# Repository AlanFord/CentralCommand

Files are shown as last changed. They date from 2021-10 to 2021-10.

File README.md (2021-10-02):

# CentralCommand
Central Command pcb for the Contextual Electronics class

The objective of this portion of the class was to design and build
a development board based on the STM32F030 MCU.  USB functionality
is provided via an FTDI FT232RQ device attached to USART2.
An 8Mhz external clock is provided by a crystal.  External headers
are provided for USART1, I2C2, SPI1, ADC, and a programming connection.
I2C1 functionality is provided via two JST SH connectors.  One user
LED is provided.  An on-board reset button will reset the mcu.

The board can be powered either by the USB connection or via an external power supply providing
between 3.75 and 6V.  The voltage regulator can provide a maximum of
250 mA at 3.3V.

**UPDATE:**  The board should be powered through the external power connection
P202 when the board is being programmed.  If the board is powered via the USB
connector during programming, the trace between the reset button, SW301, and
the FTD232RQ USB interface must be cut.  Without cutting this trace the mcu reset
that occurs during programming will simultaneously reset the FTD232RQ device,
momentarily powering down the entire board.

**UPDATE #2:**  The firmware folders and files have been restructured
and updated to support the use of the STM32CubeIDE.  To use the IDE,
simply create a workspace and import this project.

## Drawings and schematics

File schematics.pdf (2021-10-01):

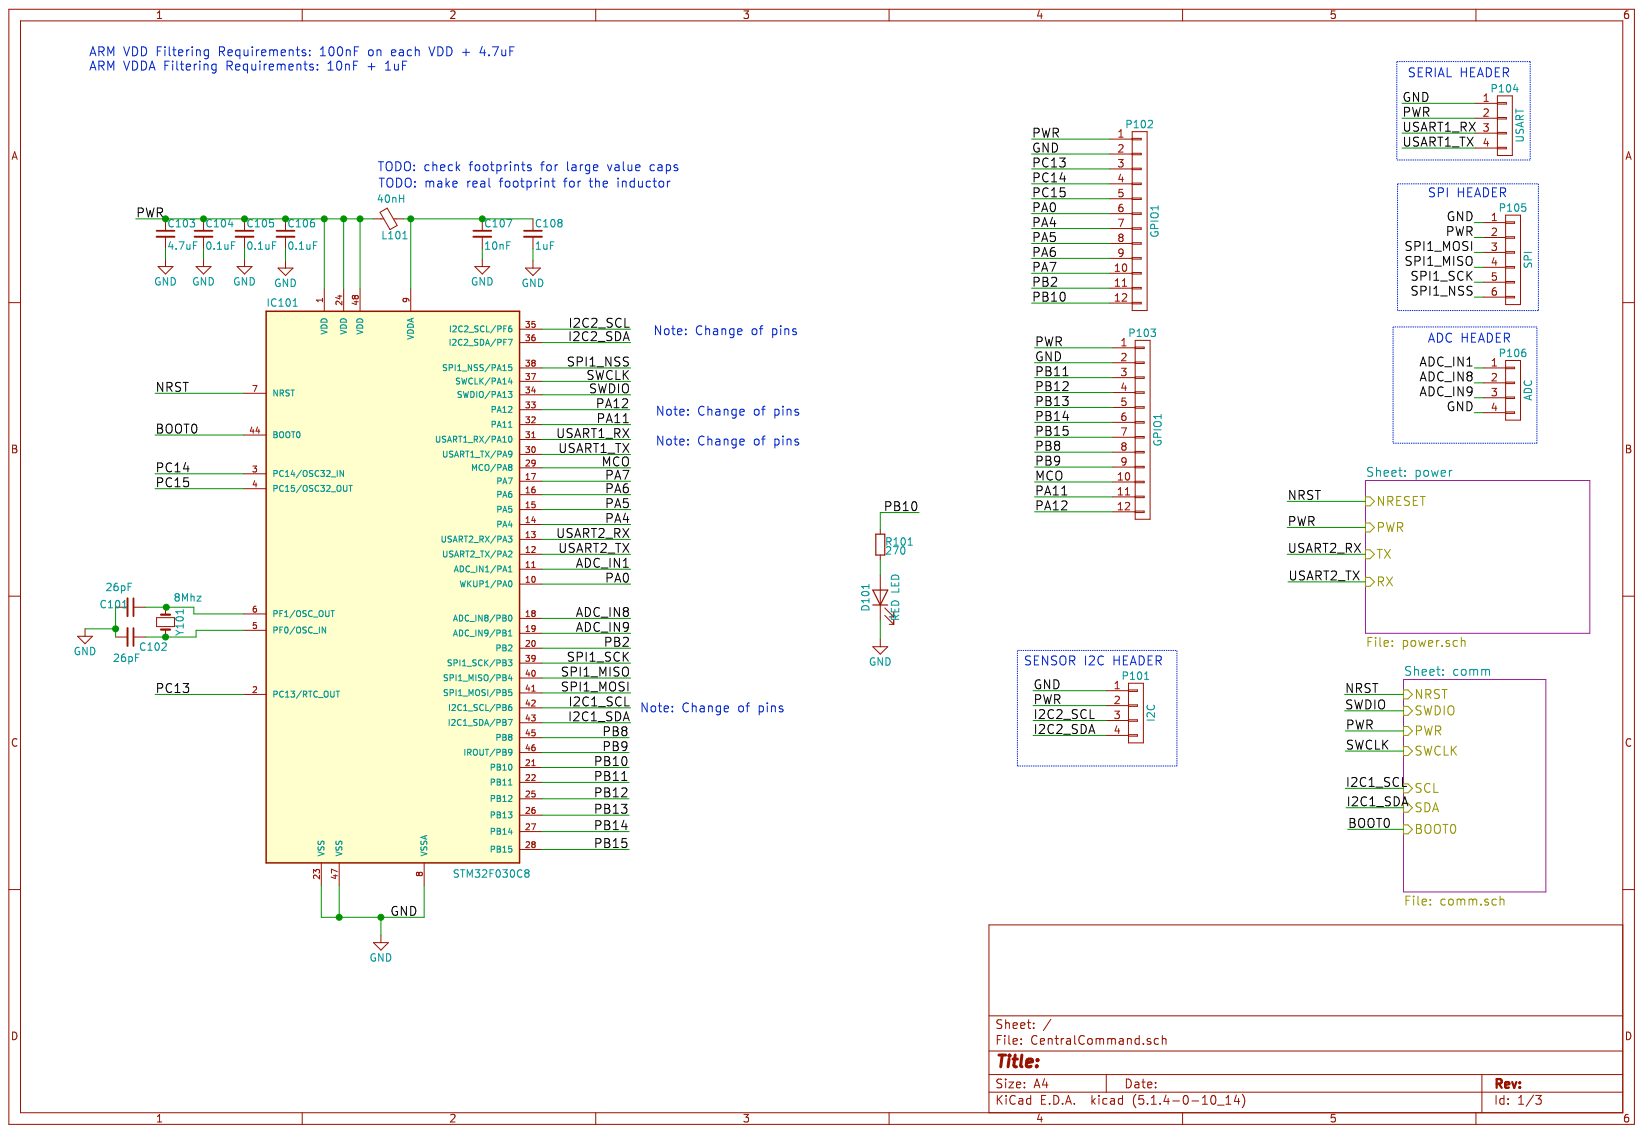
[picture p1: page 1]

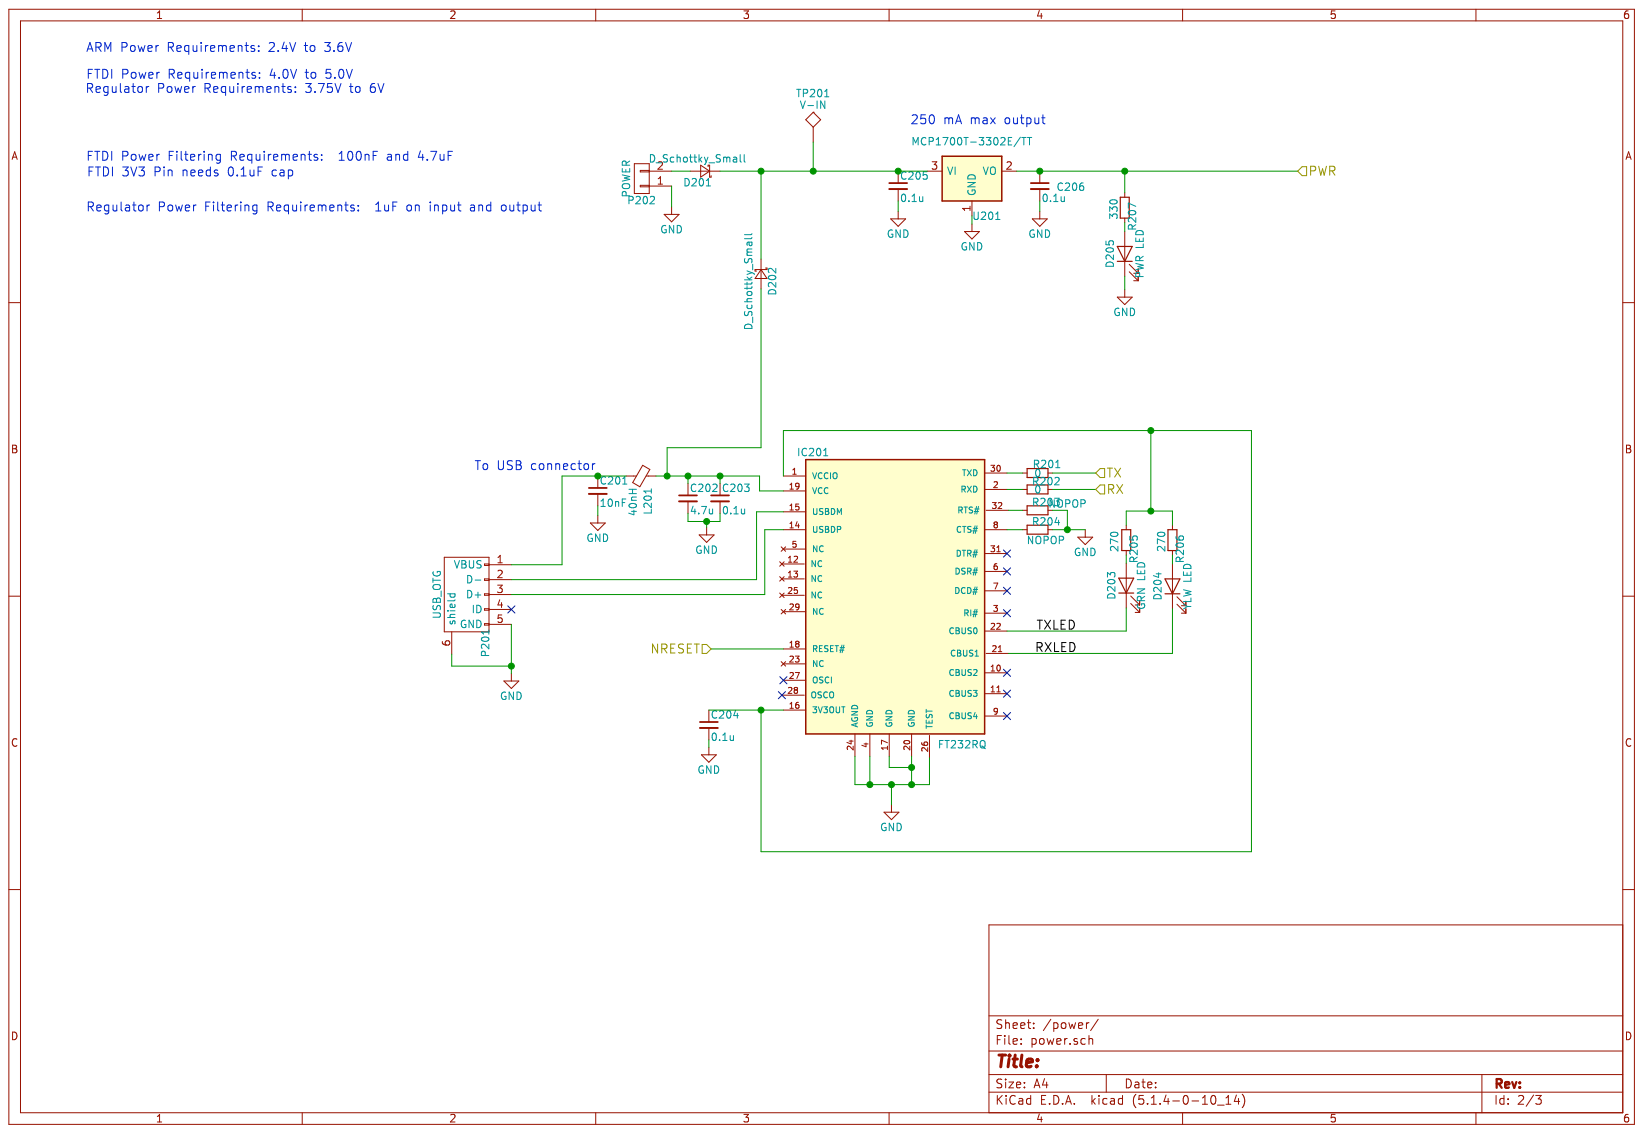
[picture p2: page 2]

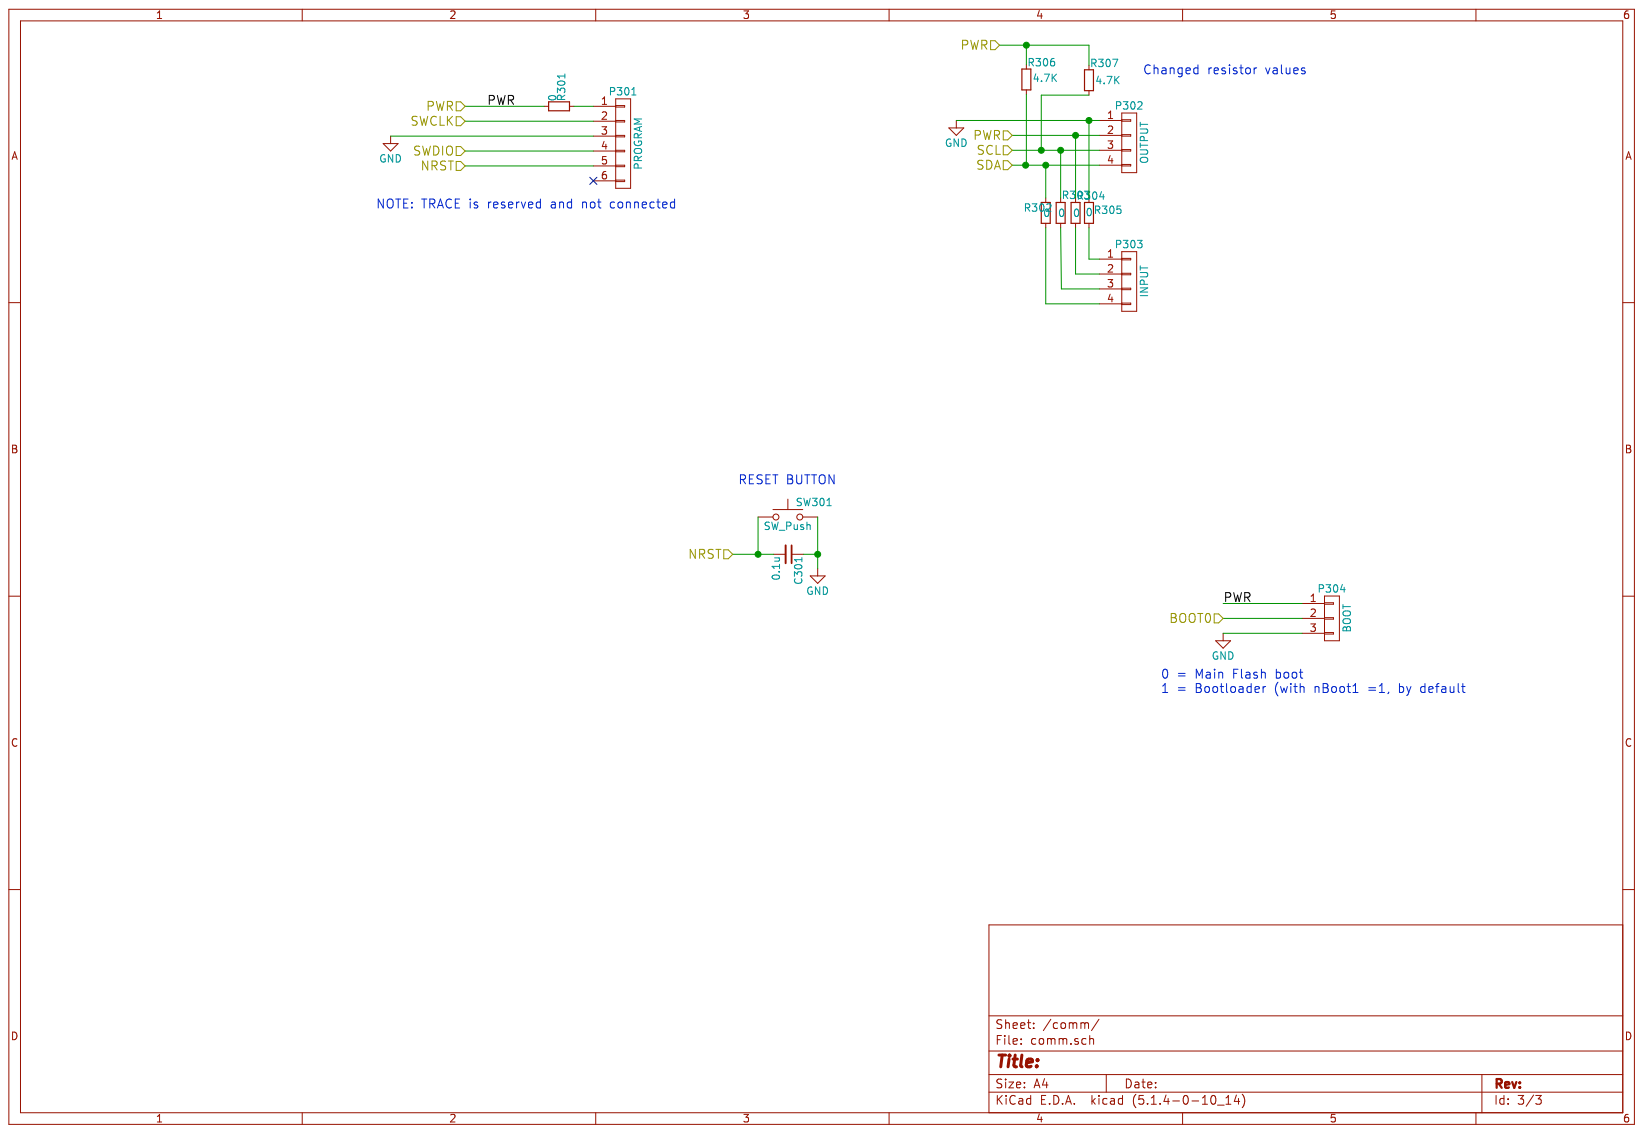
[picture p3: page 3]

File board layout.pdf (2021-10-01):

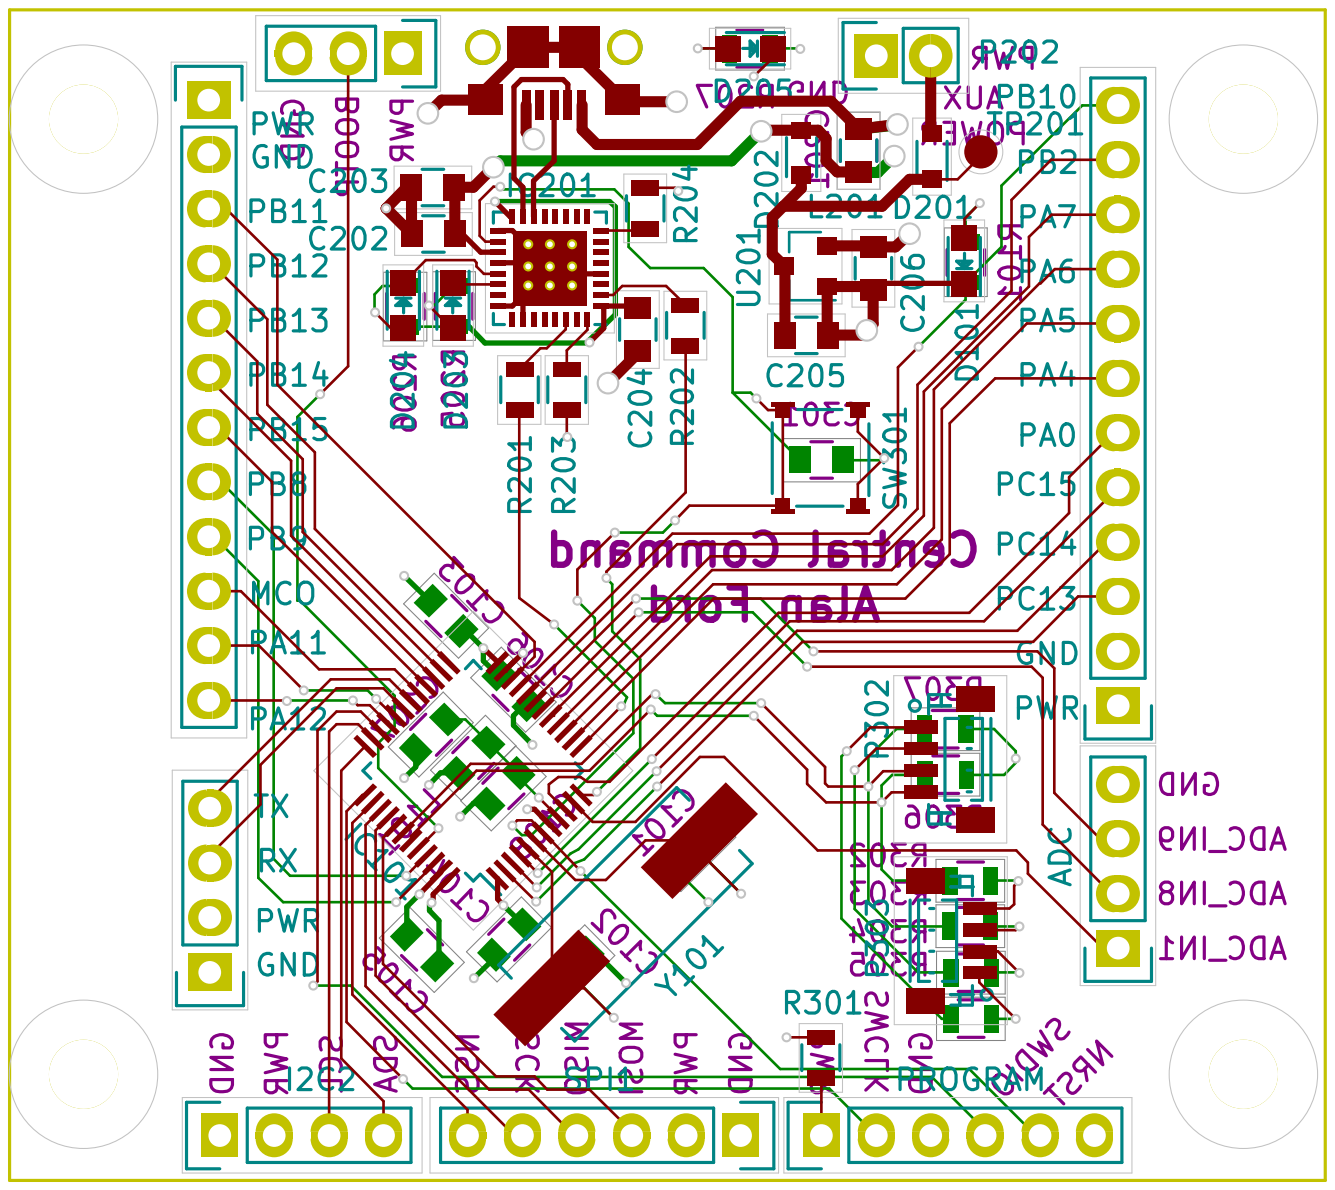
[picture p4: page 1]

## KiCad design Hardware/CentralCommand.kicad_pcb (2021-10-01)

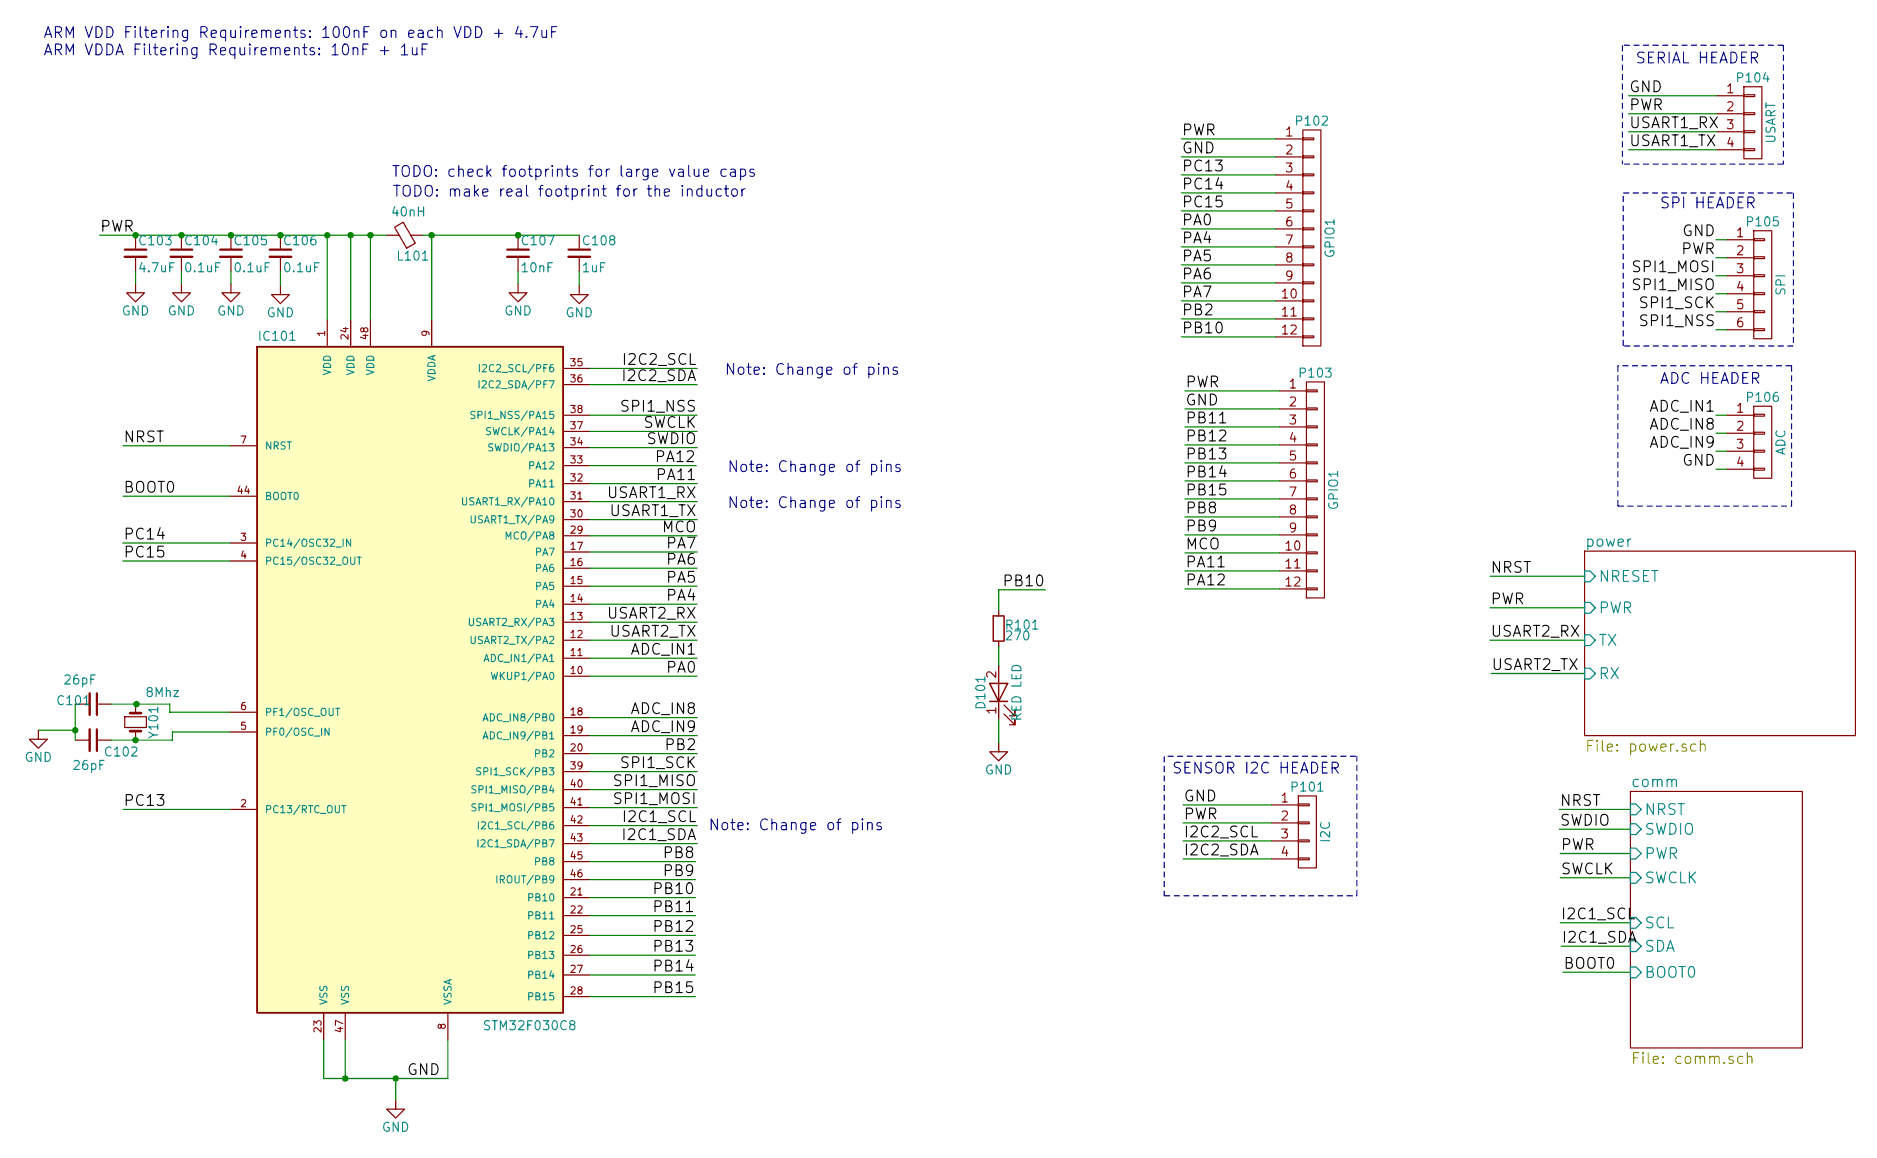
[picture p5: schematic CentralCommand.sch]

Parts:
C101, C102: 26pF; C_0805
C103: 4.7uF; C_0805
C104, C105, C106: 0.1uF; C_0805
C107: 10nF; C_0805
C108: 1uF; C_0805
D101: RED LED; LED_0805
IC101: STM32F030C8; LQFP-48_7x7mm_Pitch0.5mm; MPN STM32F030C8T6
L101: 40nH; C_0805; MPN MI0805K400R-10
P101: I2C; Pin_Header_Straight_1x04
P102, P103: GPIO1; Pin_Header_Straight_1x12
P104: USART; Pin_Header_Straight_1x04
P105: SPI; Pin_Header_Straight_1x06
P106: ADC; Pin_Header_Straight_1x04
R101: 270; R_0805
Y101: 8Mhz; Crystal_HC49-SD_SMD; MPN 9C-8.000MEEJ-T

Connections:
/ADC_IN1: IC101.11 (ADC_IN1/PA1), P106.1
/ADC_IN8: IC101.18 (ADC_IN8/PB0), P106.2
/ADC_IN9: IC101.19 (ADC_IN9/PB1), P106.3
/BOOT0: IC101.44 (BOOT0); also elsewhere on the board
/I2C1_SCL: IC101.42 (I2C1_SCL/PB6); also elsewhere on the board
/I2C1_SDA: IC101.43 (I2C1_SDA/PB7); also elsewhere on the board
/I2C2_SCL: IC101.35 (I2C2_SCL/PF6), P101.3
/I2C2_SDA: IC101.36 (I2C2_SDA/PF7), P101.4
/MCO: IC101.29 (MCO/PA8), P103.10
/NRST: IC101.7 (NRST); also elsewhere on the board
/PA0: IC101.10 (WKUP1/PA0), P102.6
/PA4: IC101.14 (PA4), P102.7
/PA5: IC101.15 (PA5), P102.8
/PA6: IC101.16 (PA6), P102.9
/PA7: IC101.17 (PA7), P102.10
/PA11: IC101.32 (PA11), P103.11
/PA12: IC101.33 (PA12), P103.12
/PB2: IC101.20 (PB2), P102.11
/PB8: IC101.45 (PB8), P103.8
/PB9: IC101.46 (IROUT/PB9), P103.9
/PB10: IC101.21 (PB10), P102.12, R101.1
/PB11: IC101.22 (PB11), P103.3
/PB12: IC101.25 (PB12), P103.4
/PB13: IC101.26 (PB13), P103.5
/PB14: IC101.27 (PB14), P103.6
/PB15: IC101.28 (PB15), P103.7
/PC13: IC101.2 (PC13/RTC_OUT), P102.3
/PC14: IC101.3 (PC14/OSC32_IN), P102.4
/PC15: IC101.4 (PC15/OSC32_OUT), P102.5
/PWR: C103.1, C104.1, C105.1, C106.1, IC101.1 (VDD), IC101.24 (VDD), IC101.48 (VDD), L101.2, P101.2, P102.1, P103.1, P104.2, P105.2; also elsewhere on the board
/SPI1_MISO: IC101.40 (SPI1_MISO/PB4), P105.4
/SPI1_MOSI: IC101.41 (SPI1_MOSI/PB5), P105.3
/SPI1_NSS: IC101.38 (SPI1_NSS/PA15), P105.6
/SPI1_SCK: IC101.39 (SPI1_SCK/PB3), P105.5
/SWCLK: IC101.37 (SWCLK/PA14); also elsewhere on the board
/SWDIO: IC101.34 (SWDIO/PA13); also elsewhere on the board
/USART1_RX: IC101.31 (USART1_RX/PA10), P104.3
/USART1_TX: IC101.30 (USART1_TX/PA9), P104.4
/USART2_RX: IC101.13 (USART2_RX/PA3); also elsewhere on the board
/USART2_TX: IC101.12 (USART2_TX/PA2); also elsewhere on the board
GND: C101.2, C102.2, C103.2, C104.2, C105.2, C106.2, C107.2, C108.2, D101.1 (K), IC101.8 (VSSA), IC101.23 (VSS), IC101.47 (VSS), P101.1, P102.2, P103.2, P104.1, P105.1, P106.4; also elsewhere on the board
unnamed: C101.1, IC101.6 (PF1/OSC_OUT), Y101.1
unnamed: C102.1, IC101.5 (PF0/OSC_IN), Y101.2
unnamed: C107.1, C108.1, IC101.9 (VDDA), L101.1
unnamed: D101.2 (A), R101.2

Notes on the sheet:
ARM VDD Filtering Requirements: 100nF on each VDD + 4.7uF ARM VDDA Filtering Requirements: 10nF + 1uF
SERIAL HEADER
SPI HEADER
ADC HEADER
SENSOR I2C HEADER
Note: Change of pins
TODO: make real footprint for the inductor
TODO: check footprints for large value caps

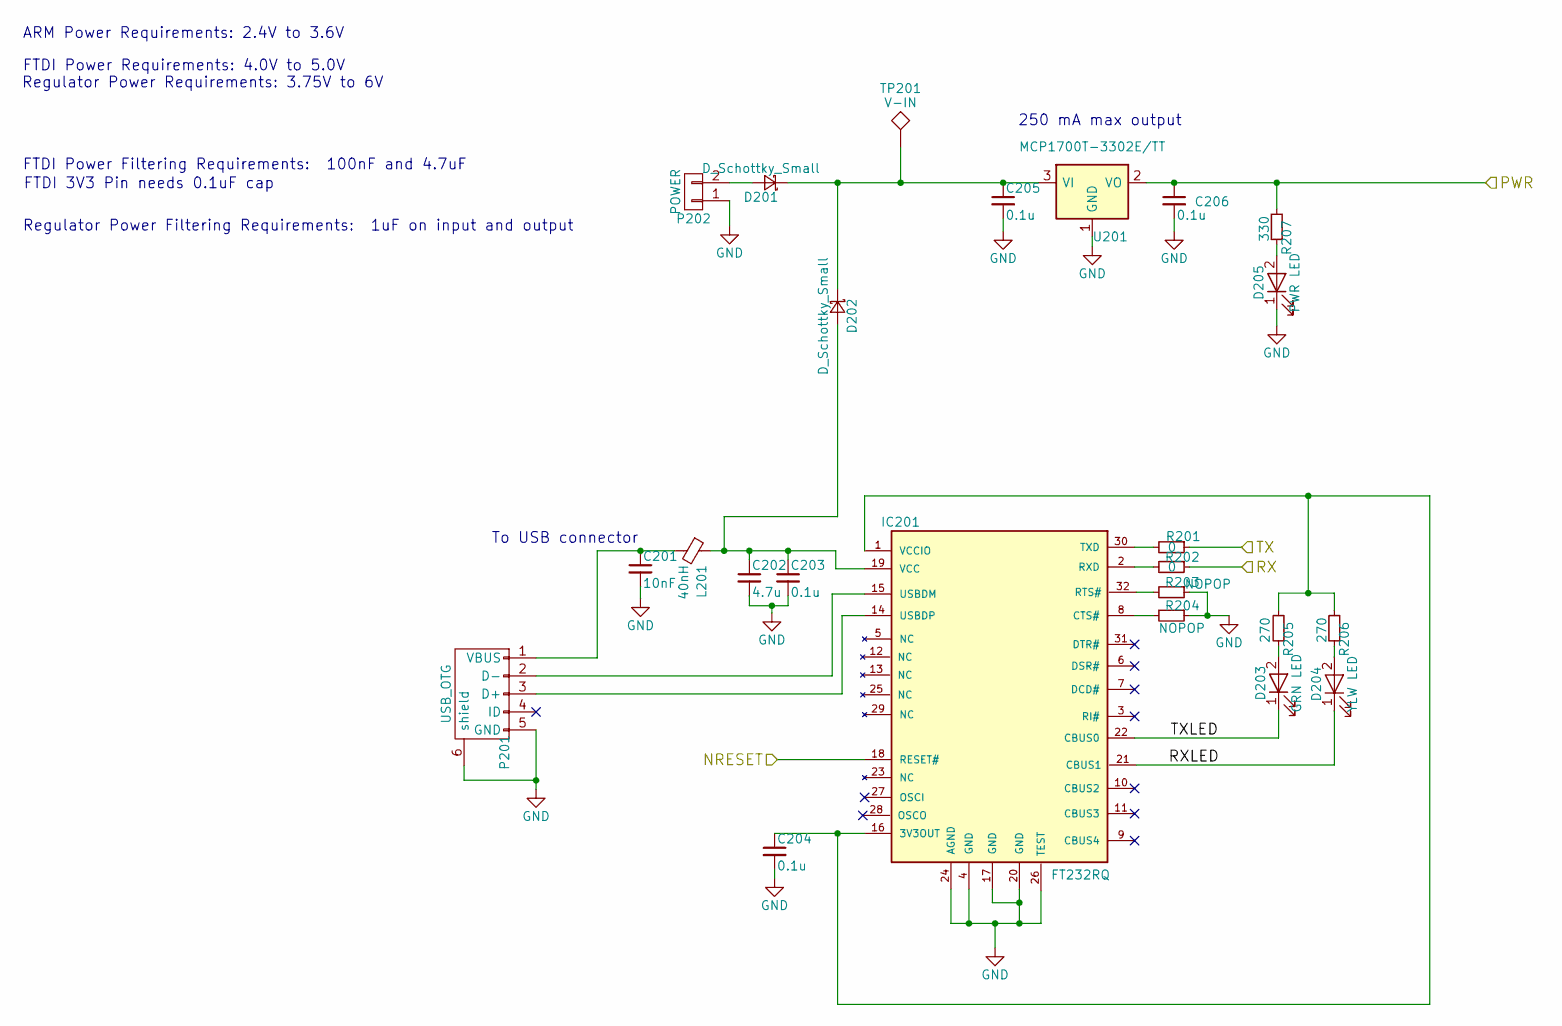
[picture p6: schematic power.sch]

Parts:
C201: 10nF; C_0805
C202: 4.7u; C_0805
C203, C204, C205, C206: 0.1u; C_0805
D201, D202: D_Schottky_Small; D_0805; MPN SK310A-TP
D203: GRN LED; LED_0805; MPN LTST-C171GKT
D204: YLW LED; LED_0805; MPN LTST-C171GKT
D205: PWR LED; LED_0805; MPN LTST-C171GKT
IC201: FT232RQ
L201: 40nH; C_0805; MPN MI0805K400R-10
P201: USB_OTG; 10118193; MPN 10118193-0001LF
P202: POWER; Pin_Header_Straight_1x02
R201, R202: 0; R_0805
R203, R204: NOPOP; R_0805
R205, R206: 270; R_0805
R207: 330; R_0805
TP201: V-IN; Measurement_Point_Round-SMD-Pad_Small
U201: MCP1700T-3302E/TT; SOT-23

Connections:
/NRST: IC201.18 (RESET#); also elsewhere on the board
/PWR: C206.1, R207.2, U201.2 (VO); also elsewhere on the board
/USART2_RX: R201.1; also elsewhere on the board
/USART2_TX: R202.1; also elsewhere on the board
/power/RXLED: D204.1 (K), IC201.21 (CBUS1)
/power/TXLED: D203.1 (K), IC201.22 (CBUS0)
GND: C201.2, C202.2, C203.2, C204.2, C205.2, C206.2, D205.1 (K), IC201.4 (GND), IC201.17 (GND), IC201.20 (GND), IC201.24 (AGND), IC201.26 (TEST), P201.5 (GND), P201.6 (shield), P202.1, R203.1, R204.1, U201.1 (GND); also elsewhere on the board
unnamed: C201.1, L201.2, P201.1 (VBUS)
unnamed: C202.1, C203.1, D202.2 (A), IC201.19 (VCC), L201.1
unnamed: C204.1, IC201.1 (VCCIO), IC201.16 (3V3OUT), R205.2, R206.2
unnamed: C205.1, D201.1 (K), D202.1 (K), TP201.1, U201.3 (VI)
unnamed: D201.2 (A), P202.2
unnamed: D203.2 (A), R205.1
unnamed: D204.2 (A), R206.1
unnamed: D205.2 (A), R207.1
unnamed: IC201.2 (RXD), R202.2
unnamed: IC201.8 (CTS#), R204.2
unnamed: IC201.14 (USBDP), P201.3 (D+)
unnamed: IC201.15 (USBDM), P201.2 (D-)
unnamed: IC201.30 (TXD), R201.2
unnamed: IC201.32 (RTS#), R203.2

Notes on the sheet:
ARM Power Requirements: 2.4V to 3.6V
FTDI Power Filtering Requirements: 100nF and 4.7uF
FTDI Power Requirements: 4.0V to 5.0V
Regulator Power Requirements: 3.75V to 6V
Regulator Power Filtering Requirements: 1uF on input and output
FTDI 3V3 Pin needs 0.1uF cap
To USB connector
250 mA max output

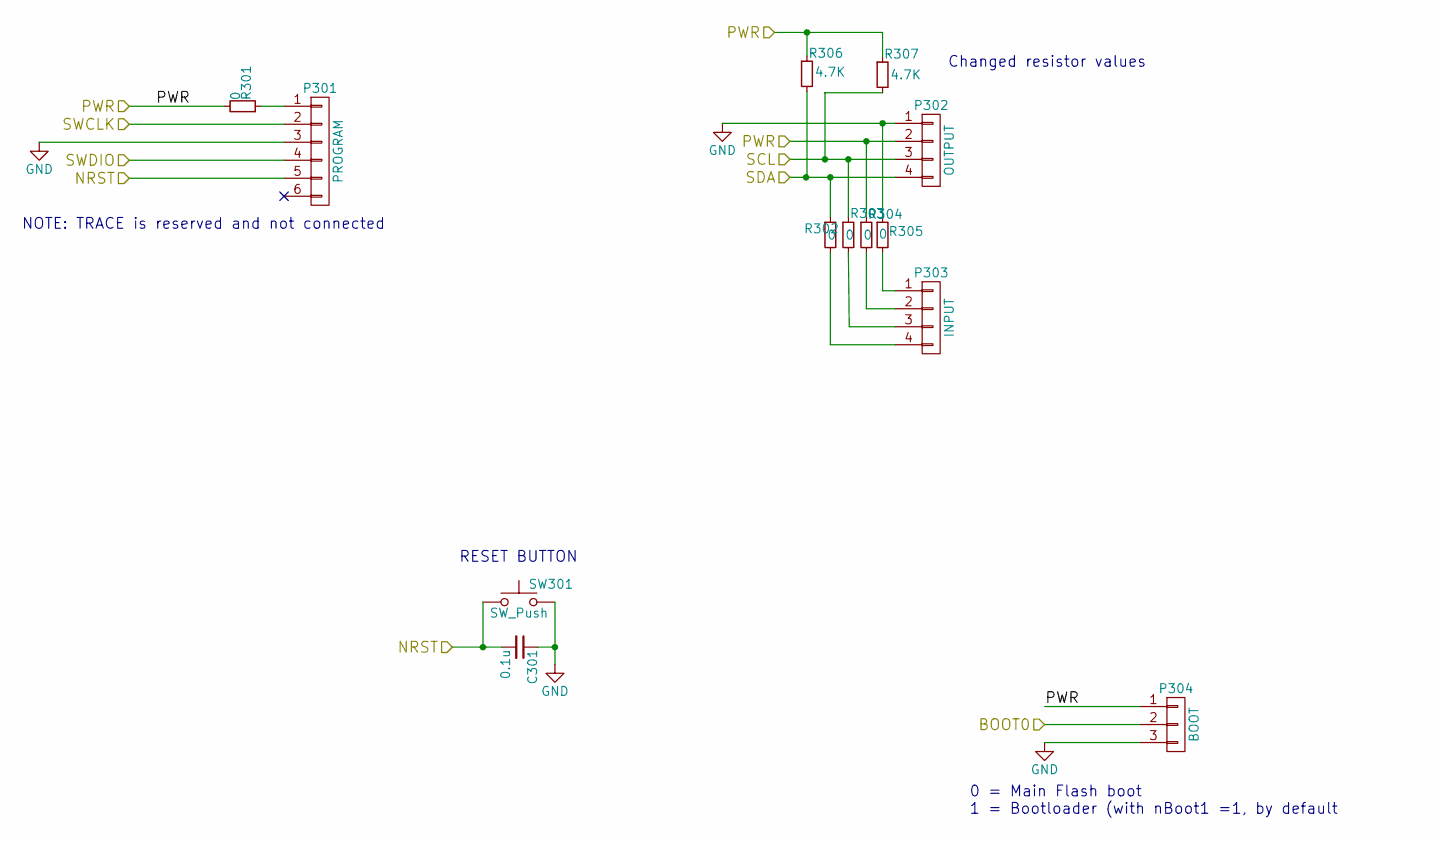
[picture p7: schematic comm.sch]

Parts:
C301: 0.1u; C_0805
P301: PROGRAM; Pin_Header_Straight_1x06
P302: OUTPUT; JST_SH_BM04B-SRSS-TB_04x1.00mm_Straight; MPN BM04B-SRSS-TB(LF)(SN)
P303: INPUT; JST_SH_BM04B-SRSS-TB_04x1.00mm_Straight; MPN BM04B-SRSS-TB(LF)(SN)
P304: BOOT; Pin_Header_Straight_1x03
R301, R302, R303, R304, R305: 0; R_0805
R306, R307: 4.7K; R_0805
SW301: SW_Push; TL3315; MPN TL3315NF100Q

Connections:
/BOOT0: P304.2; also elsewhere on the board
/I2C1_SCL: P302.3, R303.1, R307.2; also elsewhere on the board
/I2C1_SDA: P302.4, R302.1, R306.2; also elsewhere on the board
/NRST: C301.2, P301.5, SW301.1; also elsewhere on the board
/PWR: P302.2, P304.1, R301.2, R304.1, R306.1, R307.1; also elsewhere on the board
/SWCLK: P301.2; also elsewhere on the board
/SWDIO: P301.4; also elsewhere on the board
GND: C301.1, P301.3, P302.1, P304.3, R305.1, SW301.2; also elsewhere on the board
unnamed: P301.1, R301.1
unnamed: P303.1, R305.2
unnamed: P303.2, R304.2
unnamed: P303.3, R303.2
unnamed: P303.4, R302.2

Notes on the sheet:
NOTE: TRACE is reserved and not connected
RESET BUTTON
0 = Main Flash boot 1 = Bootloader (with nBoot1 =1, by default
Changed resistor values

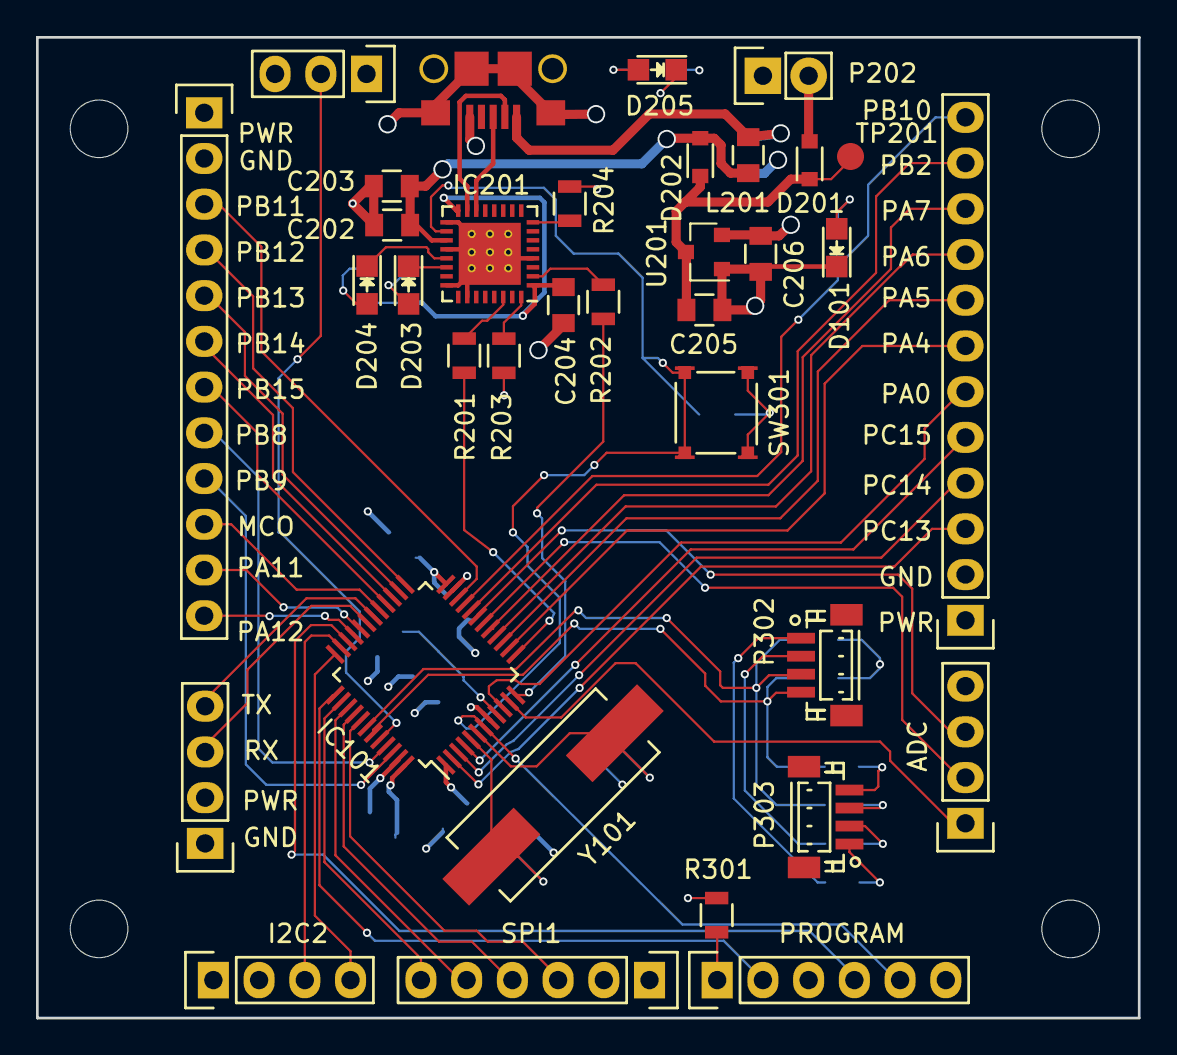
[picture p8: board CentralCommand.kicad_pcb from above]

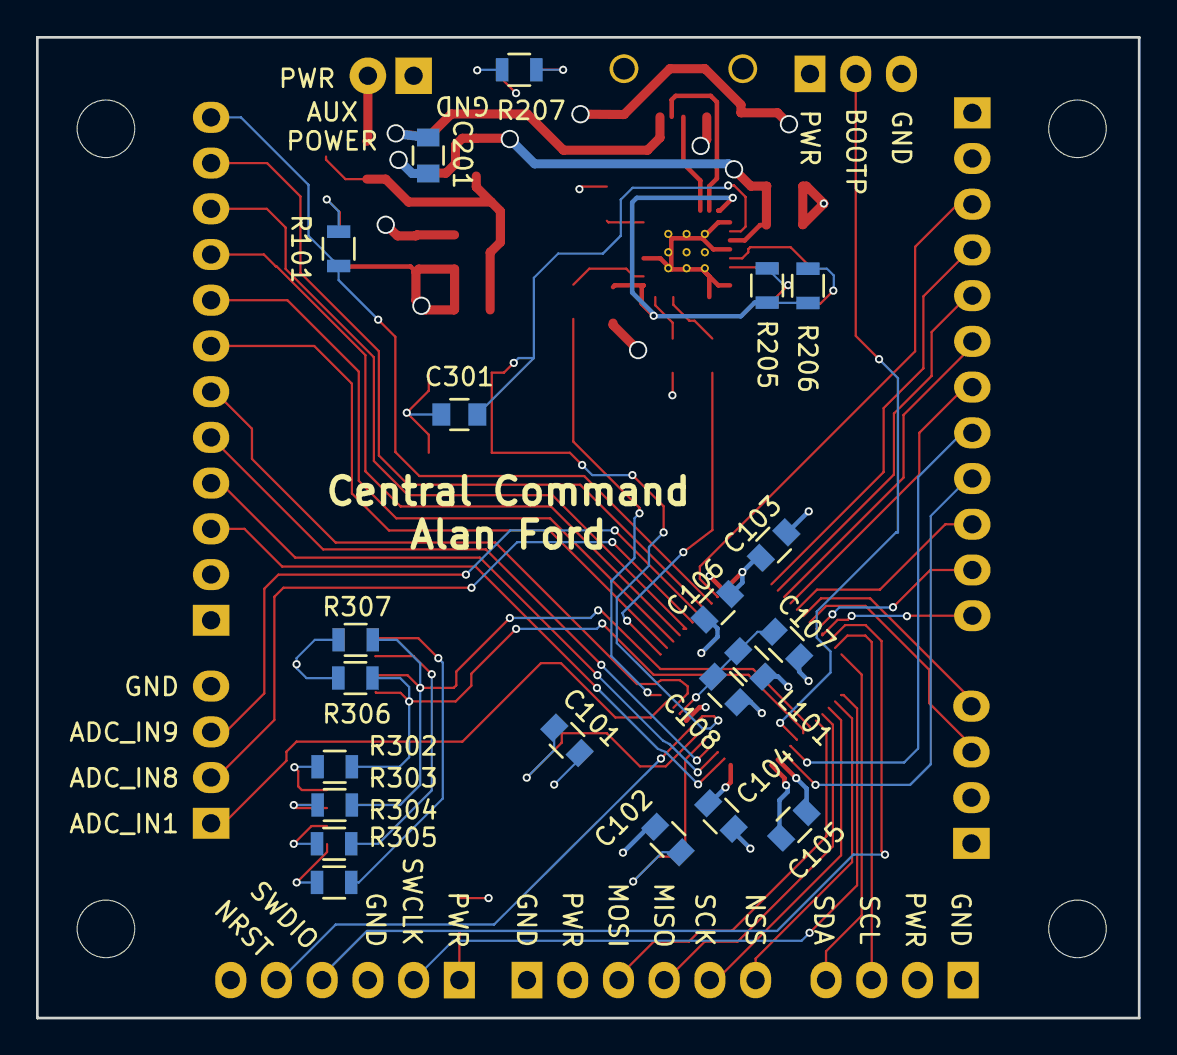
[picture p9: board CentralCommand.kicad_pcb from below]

Board: 4 copper layers, 61.2 x 54.5 mm, 56 parts (21 on the bottom side), 66 nets.

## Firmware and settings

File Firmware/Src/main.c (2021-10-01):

/////////////////////////////////////////////////////////////////////////
///	\file main.c
///	\brief This is the main program code.
///
///	\author Ronald Sousa (Opticalworm)
/////////////////////////////////////////////////////////////////////////
#include "common.h"
#include "Terminal.h"


/////////////////////////////////////////////////////////////////////////
///	\brief the first user code function to be called after the ARM M0
///	has initial.
/////////////////////////////////////////////////////////////////////////
int main(void)
{
    Terminal_Init();

    for ( ;; )
    {
    	Terminal_Process();
    }
}

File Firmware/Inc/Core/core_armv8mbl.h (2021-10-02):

/**************************************************************************//**
 * @file     core_armv8mbl.h
 * @brief    CMSIS Armv8-M Baseline Core Peripheral Access Layer Header File
 * @version  V5.0.7
 * @date     22. June 2018
 ******************************************************************************/
/*
 * Copyright (c) 2009-2018 Arm Limited. All rights reserved.
 *
 * SPDX-License-Identifier: Apache-2.0
 *
 * Licensed under the Apache License, Version 2.0 (the License); you may
 * not use this file except in compliance with the License.
 * You may obtain a copy of the License at
 *
 * www.apache.org/licenses/LICENSE-2.0
 *
 * Unless required by applicable law or agreed to in writing, software
 * distributed under the License is distributed on an AS IS BASIS, WITHOUT
 * WARRANTIES OR CONDITIONS OF ANY KIND, either express or implied.
 * See the License for the specific language governing permissions and
 * limitations under the License.
 */

#if   defined ( __ICCARM__ )
  #pragma system_include         /* treat file as system include file for MISRA check */
#elif defined (__clang__)
  #pragma clang system_header   /* treat file as system include file */
#endif

#ifndef __CORE_ARMV8MBL_H_GENERIC
#define __CORE_ARMV8MBL_H_GENERIC

#include <stdint.h>

#ifdef __cplusplus
 extern "C" {
#endif

/**
  \page CMSIS_MISRA_Exceptions  MISRA-C:2004 Compliance Exceptions
  CMSIS violates the following MISRA-C:2004 rules:

   \li Required Rule 8.5, object/function definition in header file.<br>
     Function definitions in header files are used to allow 'inlining'.

   \li Required Rule 18.4, declaration of union type or object of union type: '{...}'.<br>
     Unions are used for effective representation of core registers.

   \li Advisory Rule 19.7, Function-like macro defined.<br>
     Function-like macros are used to allow more efficient code.
 */


/*******************************************************************************
 *                 CMSIS definitions
 ******************************************************************************/
/**
  \ingroup Cortex_ARMv8MBL
  @{
 */

#include <Core/cmsis_version.h>

/*  CMSIS definitions */
#define __ARMv8MBL_CMSIS_VERSION_MAIN  (__CM_CMSIS_VERSION_MAIN)                   /*!< \deprecated [31:16] CMSIS HAL main version */
#define __ARMv8MBL_CMSIS_VERSION_SUB   (__CM_CMSIS_VERSION_SUB)                    /*!< \deprecated [15:0]  CMSIS HAL sub version */
#define __ARMv8MBL_CMSIS_VERSION       ((__ARMv8MBL_CMSIS_VERSION_MAIN << 16U) | \
                                         __ARMv8MBL_CMSIS_VERSION_SUB           )  /*!< \deprecated CMSIS HAL version number */

#define __CORTEX_M                     ( 2U)                                            /*!< Cortex-M Core */

/** __FPU_USED indicates whether an FPU is used or not.
    This core does not support an FPU at all
*/
#define __FPU_USED       0U

#if defined ( __CC_ARM )
  #if defined __TARGET_FPU_VFP
    #error "Compiler generates FPU instructions for a device without an FPU (check __FPU_PRESENT)"
  #endif

#elif defined (__ARMCC_VERSION) && (__ARMCC_VERSION >= 6010050)
  #if defined __ARM_PCS_VFP
    #error "Compiler generates FPU instructions for a device without an FPU (check __FPU_PRESENT)"
  #endif

#elif defined ( __GNUC__ )
  #if defined (__VFP_FP__) && !defined(__SOFTFP__)
    #error "Compiler generates FPU instructions for a device without an FPU (check __FPU_PRESENT)"
  #endif

#elif defined ( __ICCARM__ )
  #if defined __ARMVFP__
    #error "Compiler generates FPU instructions for a device without an FPU (check __FPU_PRESENT)"
  #endif

#elif defined ( __TI_ARM__ )
  #if defined __TI_VFP_SUPPORT__
    #error "Compiler generates FPU instructions for a device without an FPU (check __FPU_PRESENT)"
  #endif

#elif defined ( __TASKING__ )
  #if defined __FPU_VFP__
    #error "Compiler generates FPU instructions for a device without an FPU (check __FPU_PRESENT)"
  #endif

#elif defined ( __CSMC__ )
  #if ( __CSMC__ & 0x400U)
    #error "Compiler generates FPU instructions for a device without an FPU (check __FPU_PRESENT)"
  #endif

#endif

#include <Core/cmsis_compiler.h>               /* CMSIS compiler specific defines */


#ifdef __cplusplus
}
#endif

#endif /* __CORE_ARMV8MBL_H_GENERIC */

#ifndef __CMSIS_GENERIC

#ifndef __CORE_ARMV8MBL_H_DEPENDANT
#define __CORE_ARMV8MBL_H_DEPENDANT

#ifdef __cplusplus
 extern "C" {
#endif

/* check device defines and use defaults */
#if defined __CHECK_DEVICE_DEFINES
  #ifndef __ARMv8MBL_REV
    #define __ARMv8MBL_REV               0x0000U
    #warning "__ARMv8MBL_REV not defined in device header file; using default!"
  #endif

  #ifndef __FPU_PRESENT
    #define __FPU_PRESENT             0U
    #warning "__FPU_PRESENT not defined in device header file; using default!"
  #endif

  #ifndef __MPU_PRESENT
    #define __MPU_PRESENT             0U
    #warning "__MPU_PRESENT not defined in device header file; using default!"
  #endif

  #ifndef __SAUREGION_PRESENT
    #define __SAUREGION_PRESENT       0U
    #warning "__SAUREGION_PRESENT not defined in device header file; using default!"
  #endif

  #ifndef __VTOR_PRESENT
    #define __VTOR_PRESENT            0U
    #warning "__VTOR_PRESENT not defined in device header file; using default!"
  #endif

  #ifndef __NVIC_PRIO_BITS
    #define __NVIC_PRIO_BITS          2U
    #warning "__NVIC_PRIO_BITS not defined in device header file; using default!"
  #endif

  #ifndef __Vendor_SysTickConfig
    #define __Vendor_SysTickConfig    0U
    #warning "__Vendor_SysTickConfig not defined in device header file; using default!"
  #endif

  #ifndef __ETM_PRESENT
    #define __ETM_PRESENT             0U
    #warning "__ETM_PRESENT not defined in device header file; using default!"
  #endif

  #ifndef __MTB_PRESENT
    #define __MTB_PRESENT             0U
    #warning "__MTB_PRESENT not defined in device header file; using default!"
  #endif

#endif

/* IO definitions (access restrictions to peripheral registers) */
/**
    \defgroup CMSIS_glob_defs CMSIS Global Defines

    <strong>IO Type Qualifiers</strong> are used
    \li to specify the access to peripheral variables.
    \li for automatic generation of peripheral register debug information.
*/
#ifdef __cplusplus
  #define   __I     volatile             /*!< Defines 'read only' permissions */
#else
  #define   __I     volatile const       /*!< Defines 'read only' permissions */
#endif
#define     __O     volatile             /*!< Defines 'write only' permissions */
#define     __IO    volatile             /*!< Defines 'read / write' permissions */

/* following defines should be used for structure members */
#define     __IM     volatile const      /*! Defines 'read only' structure member permissions */
#define     __OM     volatile            /*! Defines 'write only' structure member permissions */
#define     __IOM    volatile            /*! Defines 'read / write' structure member permissions */
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

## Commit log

2017-03-25 initialized KiCad
    [CentralCommand.kicad_pcb, CentralCommand.sch]
2017-03-25 arranged things in folders
    [CentralCommand.kicad_pcb, CentralCommand.sch]
2017-03-25 added documentation and stm32 schematic symbol
    [CentralCommand.sch]
2017-03-25 udated stm32 symbol docs
2017-03-31 updated connectors and ftdi connections
    [CentralCommand.sch, comm.sch, power.sch]
2017-04-02 reassigned pin to correct I2C1, I2C2, and USART1 connections
    [CentralCommand.sch, comm.sch, power.sch]
2017-04-02 updated STM32 symbol to reflect correct pin functions
2017-04-03 initial footprint assignments
    [CentralCommand.kicad_pcb, CentralCommand.sch, comm.sch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]
2017-04-03 added crystal details and usb footprint
    [CentralCommand.kicad_pcb, CentralCommand.sch, comm.sch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]
2017-04-08 changed grove connectors to jst sh and added VCC and GND to other headers
    [CentralCommand.sch, comm.sch, power.sch]
2017-04-10 fixed jst sh headers and added button footprint
    [CentralCommand.sch, comm.sch, power.sch]
2017-05-10 started board layout
    [CentralCommand.kicad_pcb, CentralCommand.sch, comm.sch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]
2017-05-10 converted VCCIO to 3V3 and added 1x2 power and gnd
    [CentralCommand.kicad_pcb, CentralCommand.sch, comm.sch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]
2017-05-11 swapped power and gnd on gpio headers and added blinky led
    [CentralCommand.kicad_pcb, CentralCommand.sch, comm.sch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]
2017-05-14 more layout
    [CentralCommand.kicad_pcb, power.sch]
2017-05-14 moved headers from power side of boards and rerouted traces
    [CentralCommand.kicad_pcb, comm.sch, power.sch]
2017-05-27 continued pcb layout
    [CentralCommand.kicad_pcb]
2017-06-04 layout almost done
    [CentralCommand.kicad_pcb]
2017-06-20 relocated footprint labels
    [CentralCommand.kicad_pcb]
2017-06-20 labeled headers
    [CentralCommand.kicad_pcb]
2017-06-20 adjusted a few more labels, added mounting holes, generated gerbers
    [CentralCommand-B.Cu.gbl, CentralCommand-B.Mask.gbs, CentralCommand-B.Paste.gbp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]
2017-06-20 created gerber archives
2021-10-01 bring everything up-to-date
    [CentralCommand-B.Cu.gbl, CentralCommand-B.Mask.gbs, CentralCommand-B.Paste.gbp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]
2021-10-02 Restructure firmware to use STM32CubeIDE
    Fix a folder name
    [core_armv8mbl.h, core_armv8mml.h]
